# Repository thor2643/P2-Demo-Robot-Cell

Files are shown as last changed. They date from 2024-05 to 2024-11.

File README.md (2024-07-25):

# P2-Demo-Robot-Cell
This GitHub repository contains the relevant code and files for a robot demonstration cell initially developed by a second semester group at Aalborg University and later refined for robustness and visual appearance. The project aims to demonstrate how an entrance to autonomy does not necessarily have to be as expensive as one might think. This single robot cell stands in contrast to a bigger Festo demonstartion line which, like this robot cell, assembles a dummy phone. Beside this introduction to the cell, build and run instructions for the different applications are given to enable other persons or groups at Aalborg University to operate the cell. See the robot cell in action on [YouTube](https://youtu.be/gxAgMTmDVhU).
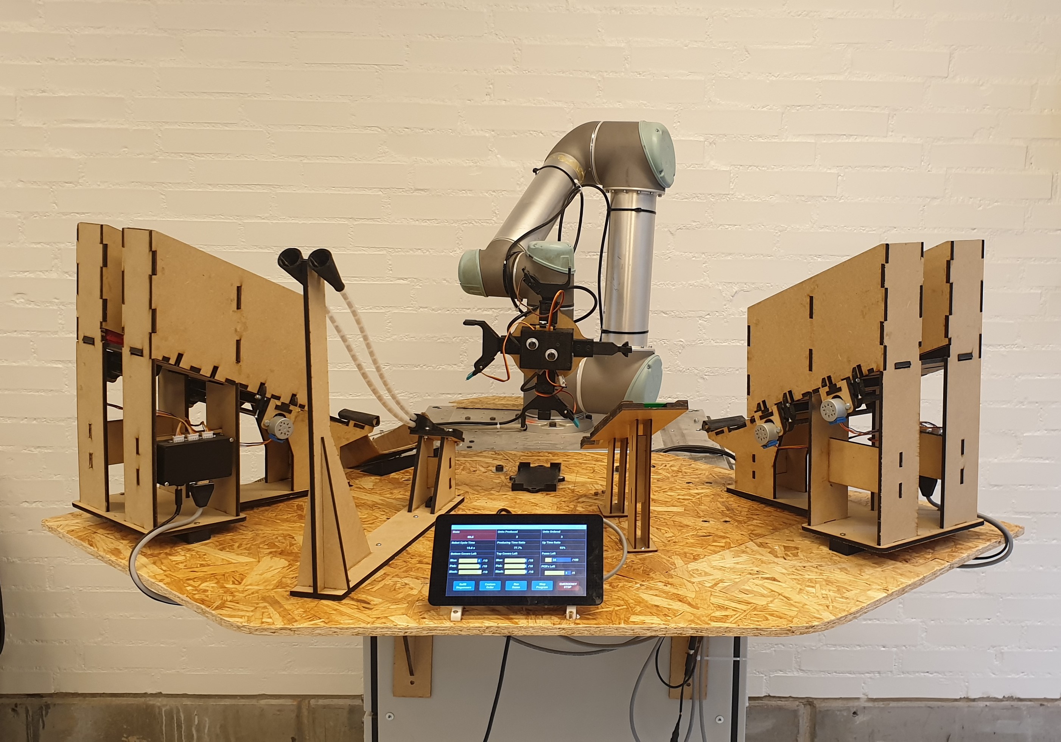
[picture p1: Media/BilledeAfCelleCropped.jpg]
Image of the whole robot cell


## How To Run the Cell
The first step to run the cell is making sure that everything is plugged in. There are three plugs that must be plugged into a power outlet: one for the robot, one for the Raspberry Pi and one for the dispensers. When the Raspberry Pi is plugged in it will automatically boot up and start the GUI application after some time. The next step is to start the right program on the UR5 robot. To do so, one must first initialise the robot by going the initialsation screen, turn ON the robot, START the robot, and holding the AUTO button until it is ready. Please notice that this old Polyscope version (1.8) moves a lot when initialising the robot, so make sure that the gripper is not close to any of the dispensers and the table; be careful when holding the AUTO button down. Before pushing AUTO the robot can be moved by hand by pushing the button on the backside of the teach pendant. Now the program can be loaded. Go to the main page and follow these steps:
1. Click "Program Robot"
2. Click "Load Program"
3. Find and open folder "P2-Demo"
4. Open "DemoProgram.urp"
5. Do not load installation file if asked (click "NO")
6. Go to "Installation" tab and choose "Load/Save" in the side panel
7. Click "Load" (Load a different installation file)
8. Open "demo.installation"
9. Go to "Program" tab and click play button to start the program

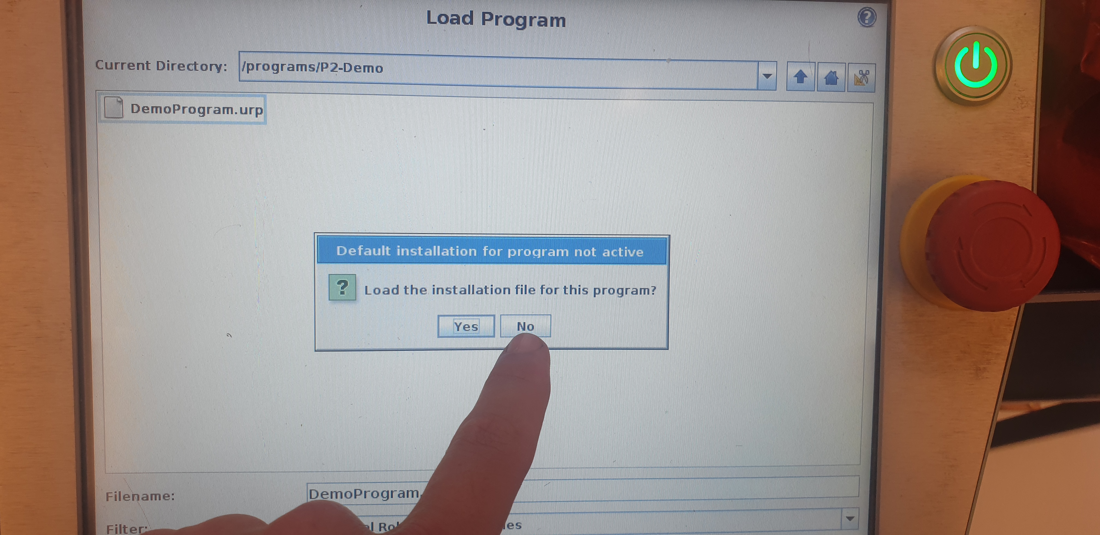
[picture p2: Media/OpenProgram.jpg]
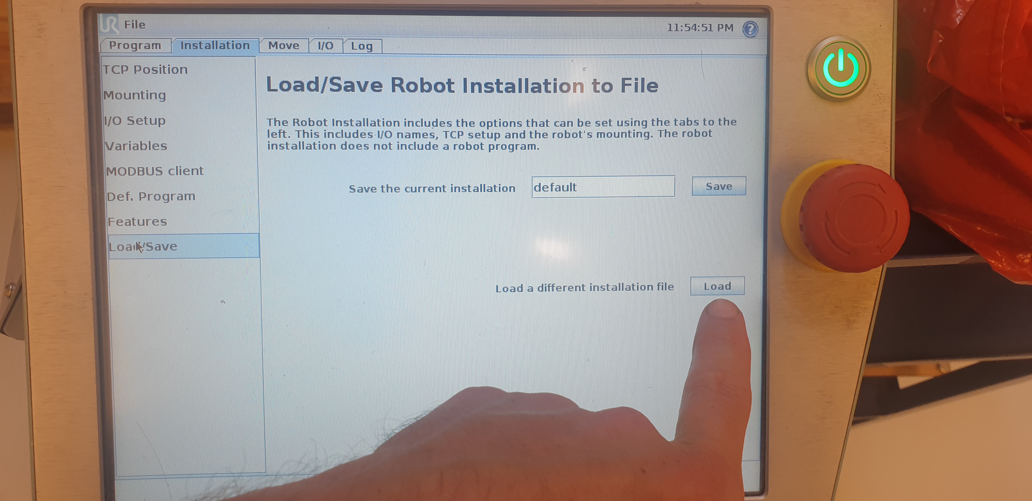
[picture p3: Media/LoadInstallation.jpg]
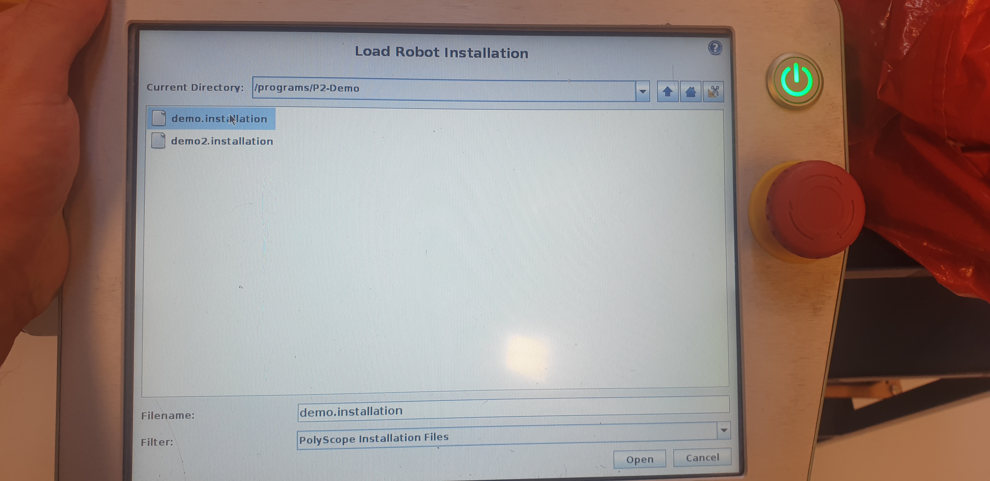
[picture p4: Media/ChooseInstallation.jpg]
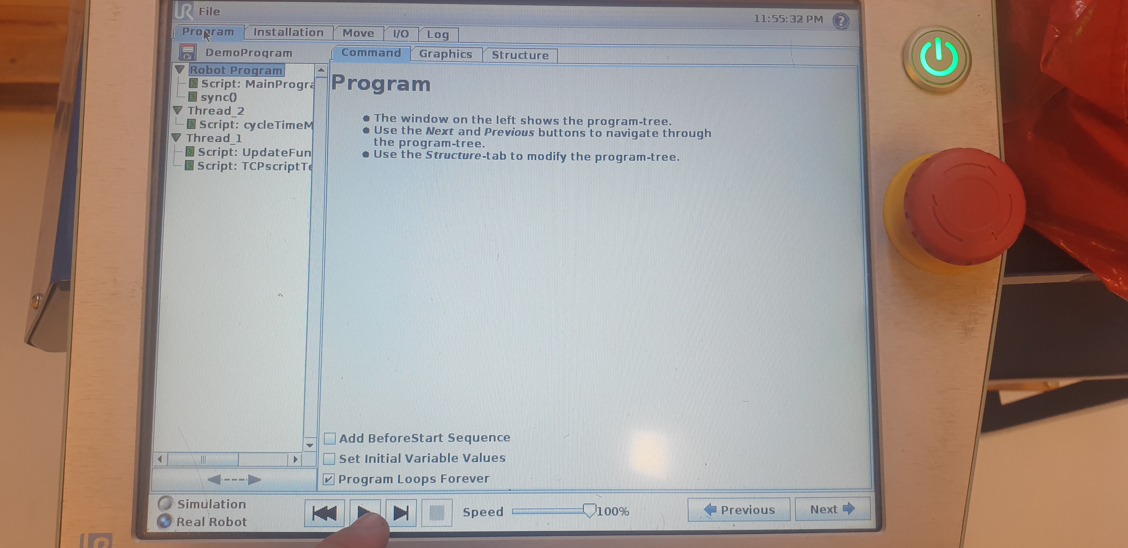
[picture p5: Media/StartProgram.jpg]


>[!Note]
>If the robot throws a force limit error the free move button on the backside must sometimes be pushed while enabling the robot to free it (can take a few tries). The socket connection to the Pi cannot always be reestablished by simply starting the program again. If this is the case the Raspberry Pi must be rebooted.
>Also please ensure that all grippers are opened before restarting program by going to the IO tab and turning ON/OFF pin 8 and 9 until all are opened.

## RoboDK 
A virtual copy of the robot cell has been created and vastly used throughout the programming of the robtos trajectory. By using the "Generate Program" feature, RoboDK generated the script, which with smaller modifications could be copied and run in the robot controller. The RoboDK station can be found in the "RoboDK" folder. To place the dispensers correctly and create proper target points a combination of the RoboDK python API and manually tweaking has been used, which has ensured a precise relation between the virtual cell and the physical cell. The created RoboDK program can, therefore, be well used if further development or modifcations to the cell setup or trajectory profile is desired. The scripts used to load and place the dispensers as well as creating the target points can be found in "Code/RoboDKScripts".
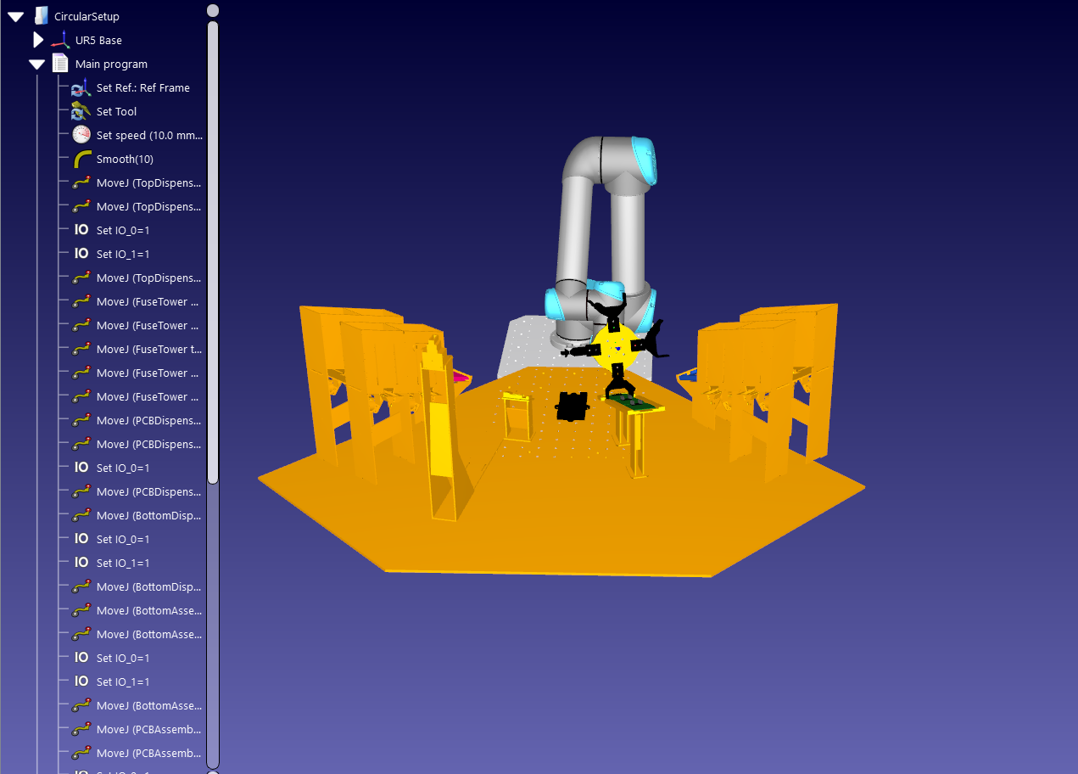
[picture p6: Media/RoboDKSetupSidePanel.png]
Screenshot of the RoboDK station.


## GUI Application Build Instructions
The GUI application has been developed to be cross-platform compatible and should therefore be buildable on both windows machines (using MSYS2) and linux machines. Build instructions are given to enable further development by other persons or groups. As an example, the custom order feature has not yet been implemented and could be a nice place to start learning about setup.  
To build the GUIServer application please refer to the comments written in "Code/TCPServer/GUIServer/MakeFile" to see GLFW dependency. When GLFW has been installed, the make command can called in the "GUIServer" folder to build the application. The executable can then be found in the test folder as GUIServerSmall.exe. 

>[!TIP]
>The App class structure for the ImGUI code has been set up following this tutorial on YouTube: [ImGUI code setup](https://www.youtube.com/watch?v=OYQp0GuoByM&t=1240s).

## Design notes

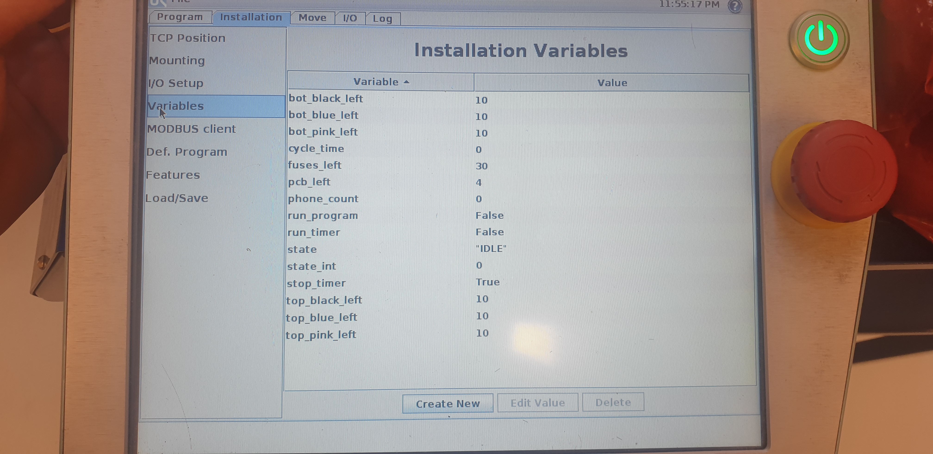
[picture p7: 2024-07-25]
Media/CheckVariables.jpg

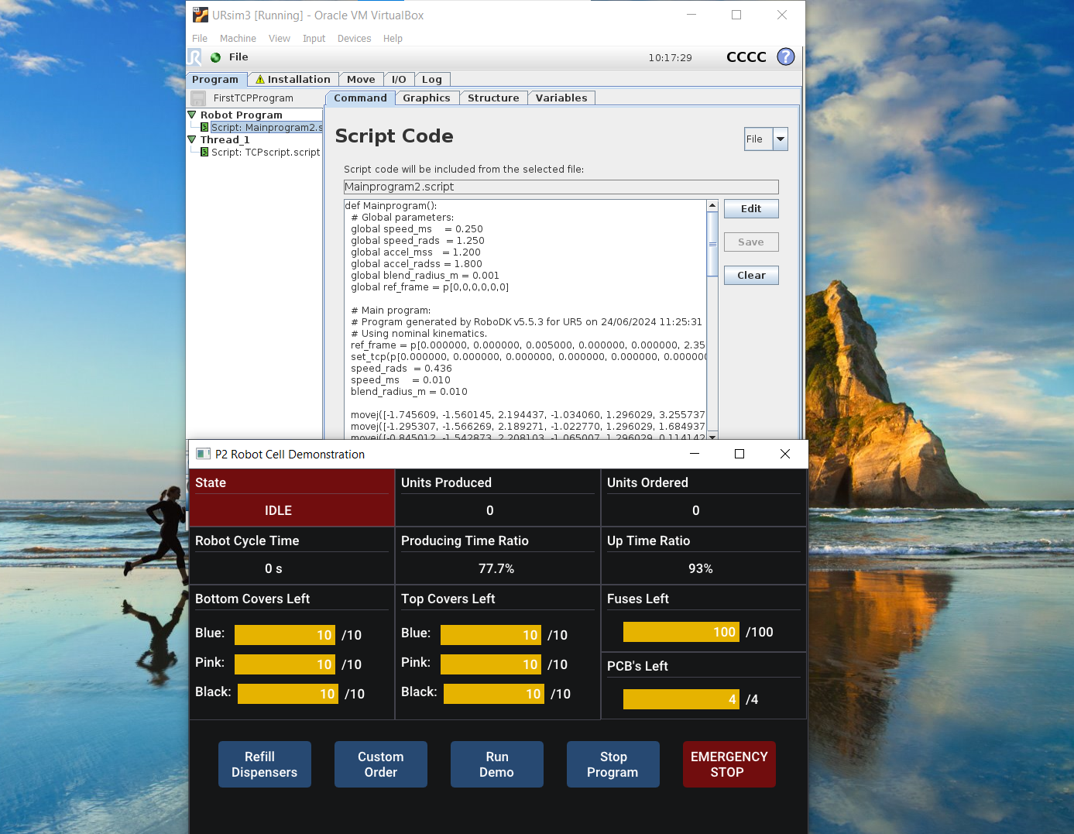
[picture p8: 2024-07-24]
Media/URSimAndGUI.png

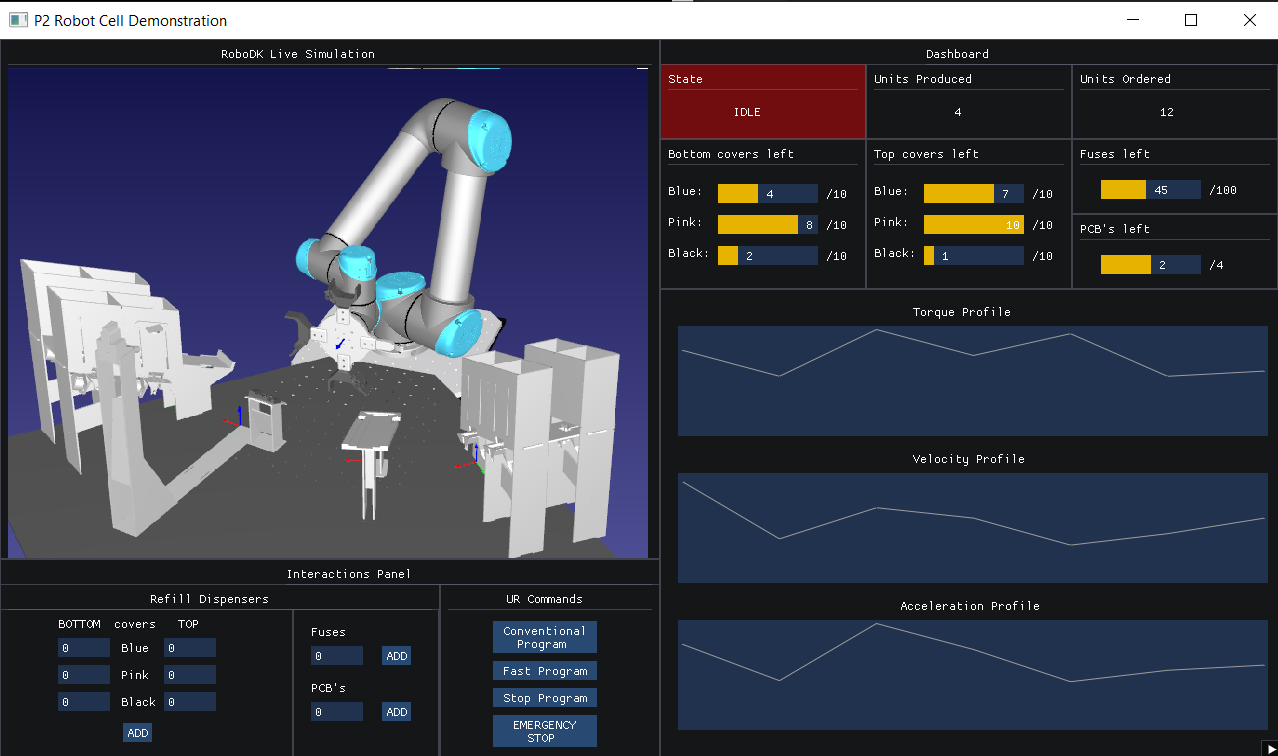
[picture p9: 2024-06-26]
Media/GUI_example.png

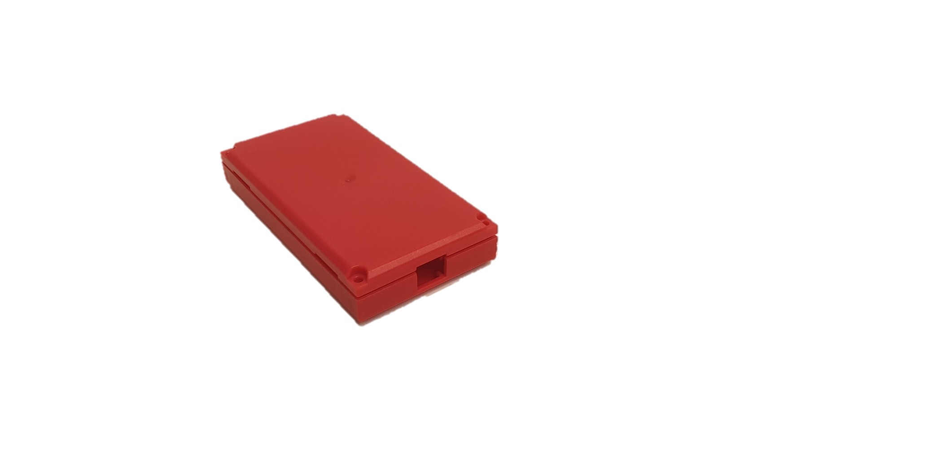
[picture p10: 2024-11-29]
Code/TCPServer/GUI_Server/resources/pink_pink.png

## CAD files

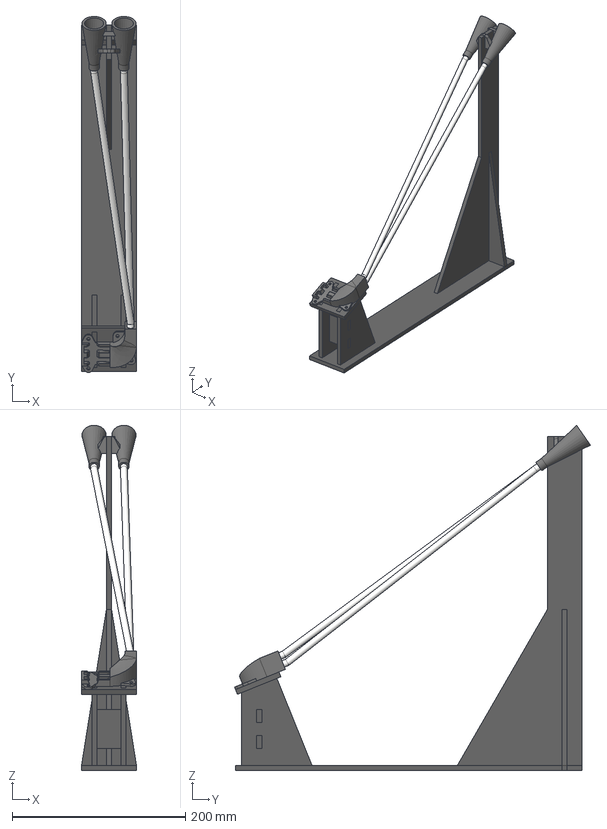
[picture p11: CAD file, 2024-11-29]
StepFiles/NewVersions/FuseDispenserAssembled.step
63.5 x 411.0 x 398.7 mm
BasePlate
LowerLegLeft
LowerLegRight
LowerSupport
Platform
UpperMainLeg
UpperSupport
FuseHolder
Funnel
PipeLeft
PipeRight

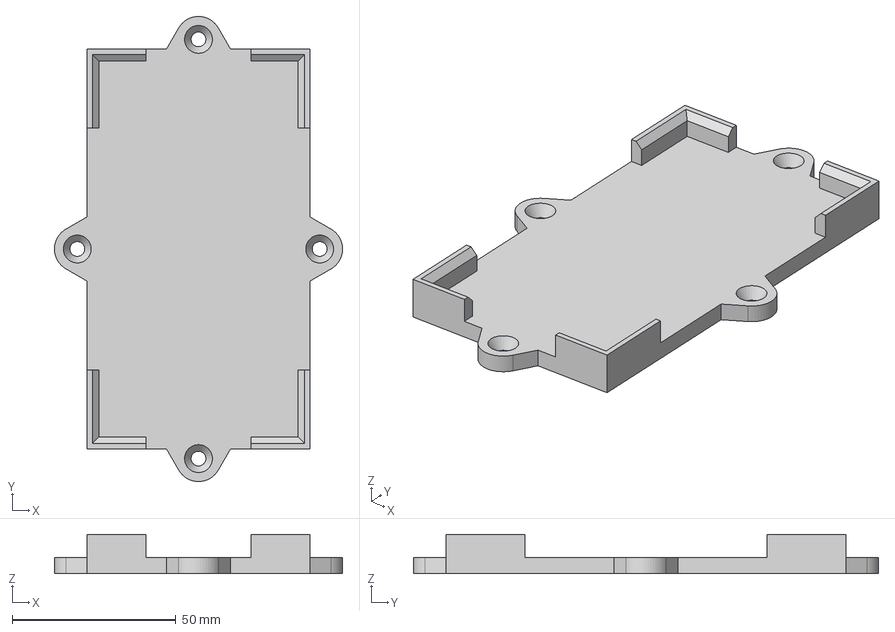
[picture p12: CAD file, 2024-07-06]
StepFiles/NewVersions/AssemblyHolder.step
88.0 x 142.0 x 12.0 mm

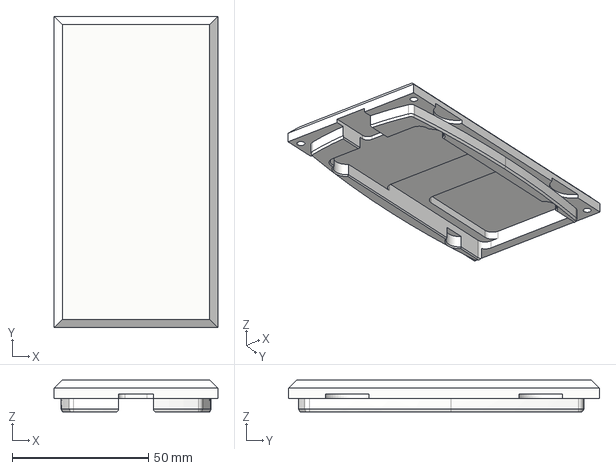
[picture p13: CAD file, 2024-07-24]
StepFiles/Top.step
60.0 x 114.0 x 11.7 mm

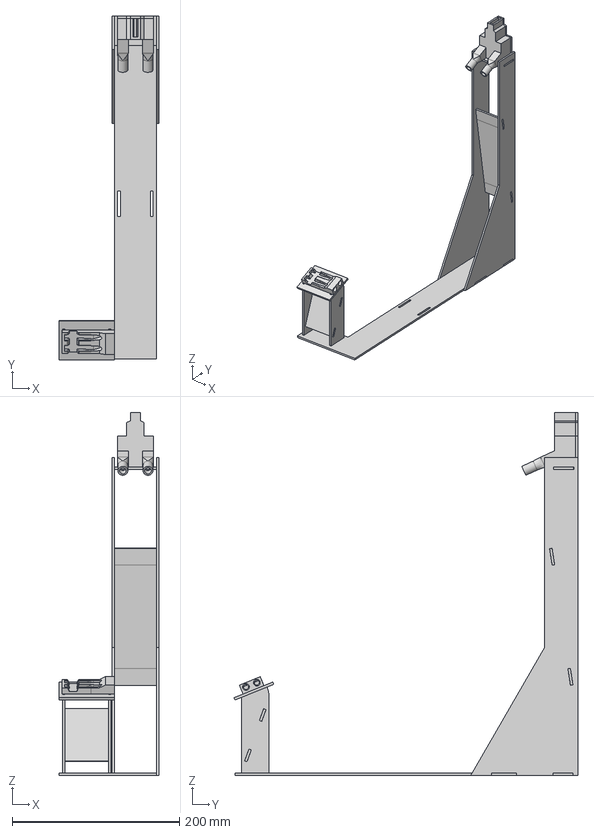
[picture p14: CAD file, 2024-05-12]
StepFiles/FuseTower.step
119.0 x 411.1 x 434.0 mm
Connection v3
Connection v3_1
Baseplate

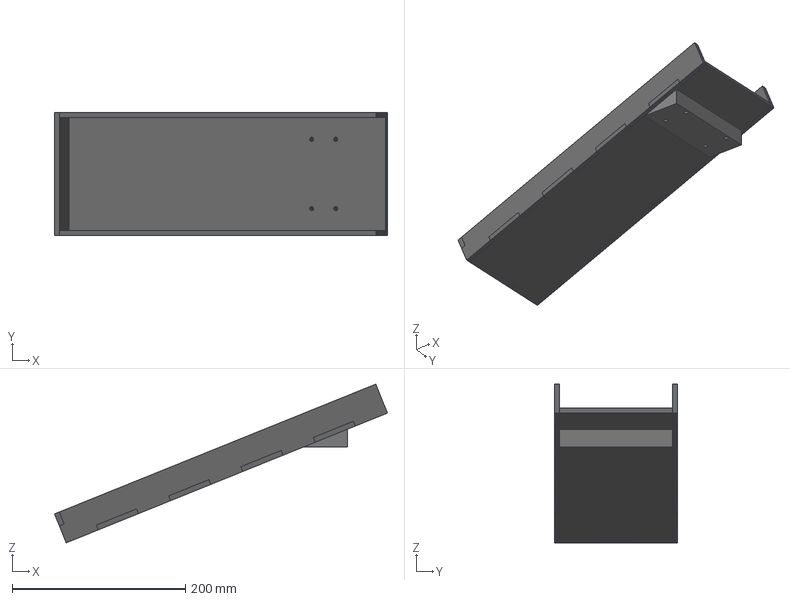
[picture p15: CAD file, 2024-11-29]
StepFiles/NewVersions/Unloader.step
384.4 x 142.0 x 183.2 mm

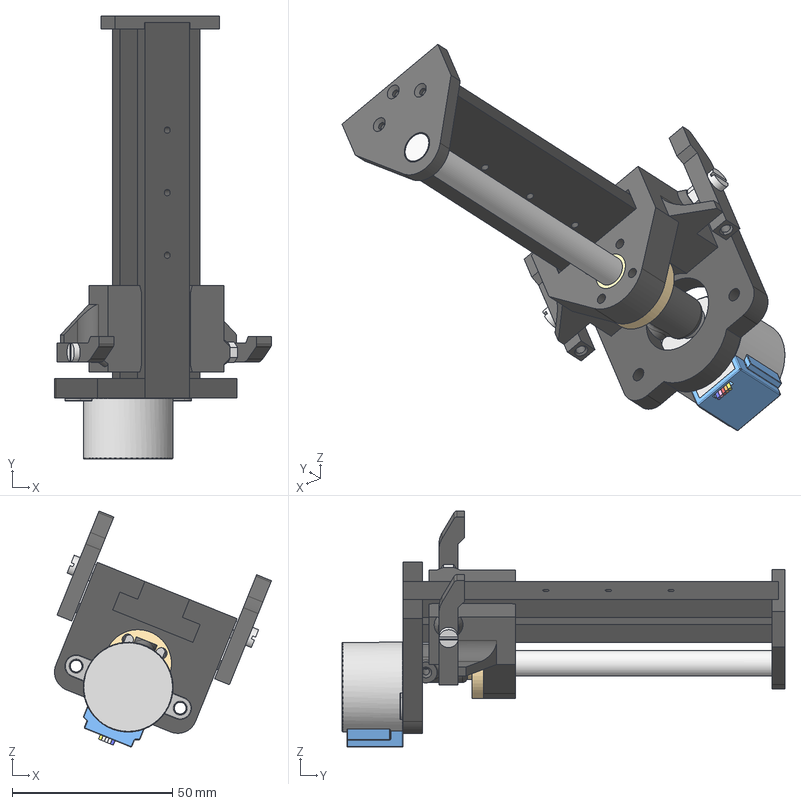
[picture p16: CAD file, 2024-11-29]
StepFiles/NewVersions/WidePusher.step
67.7 x 138.0 x 73.6 mm

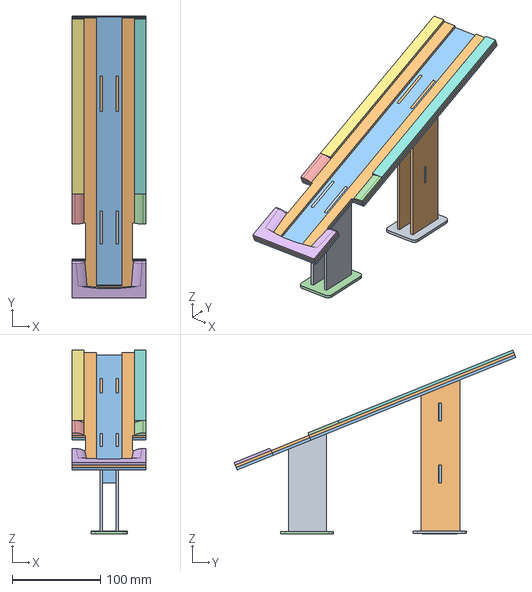
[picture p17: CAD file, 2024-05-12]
StepFiles/PCBDispenser.step
83.4 x 318.6 x 208.1 mm

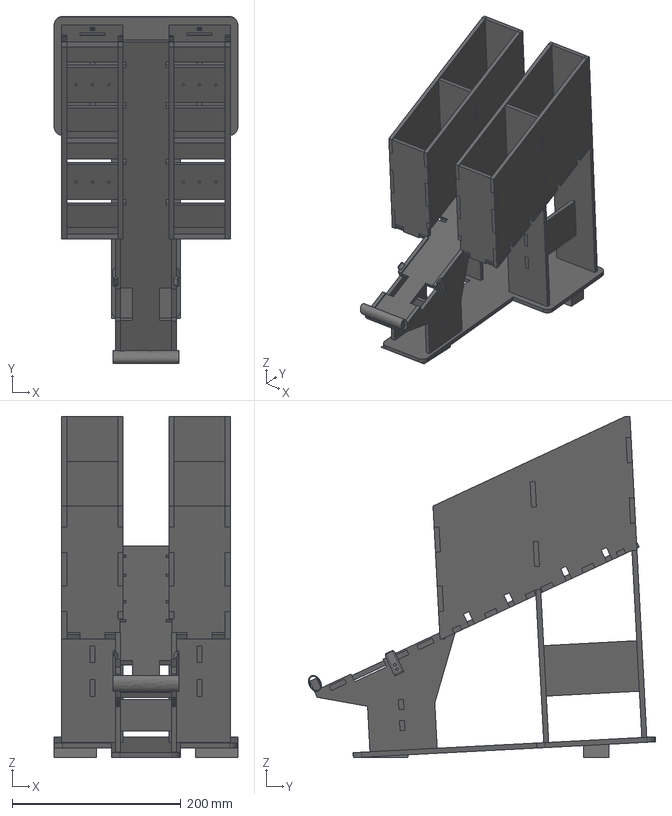
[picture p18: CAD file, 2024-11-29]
StepFiles/NewVersions/CoverContainer.step
218.0 x 411.7 x 405.0 mm

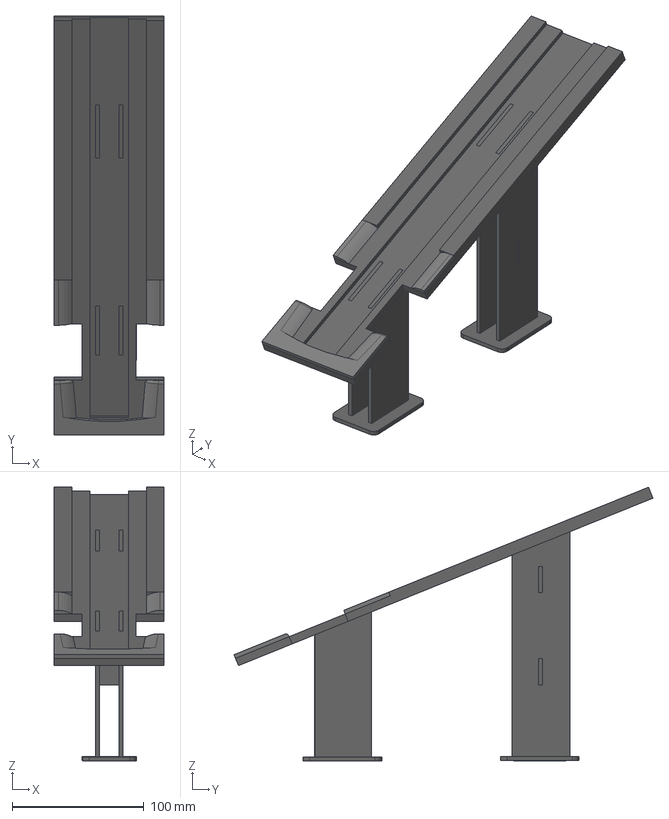
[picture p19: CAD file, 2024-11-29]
StepFiles/NewVersions/PCBSlider.step
83.4 x 318.6 x 208.1 mm

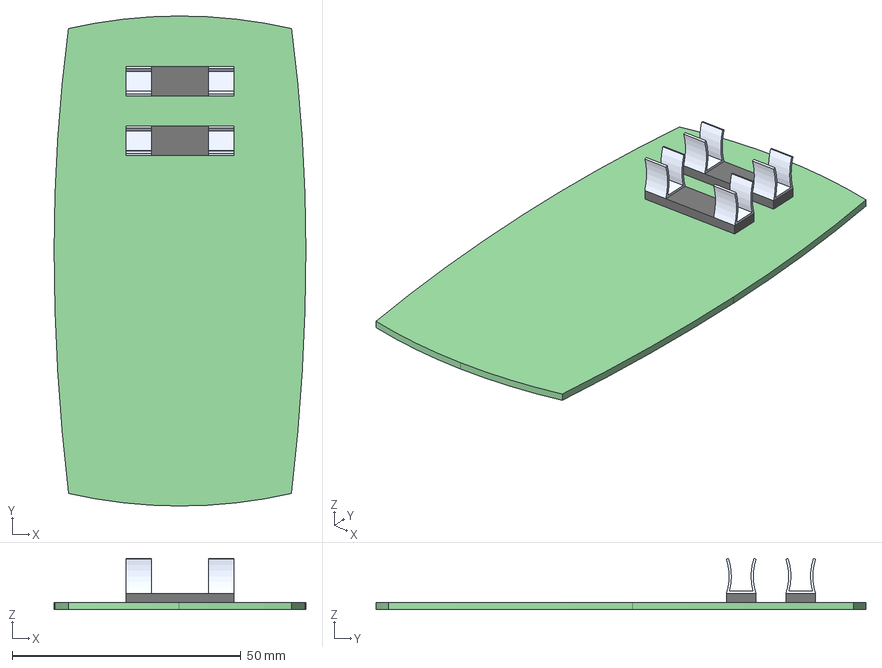
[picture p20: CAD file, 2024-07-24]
StepFiles/NewVersions/PCBBoard.step
55.0 x 107.0 x 11.2 mm

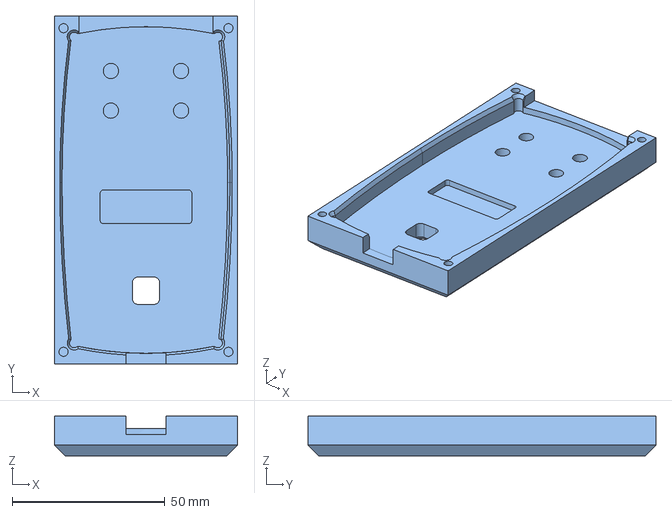
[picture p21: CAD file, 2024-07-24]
StepFiles/NewVersions/BundCover.step
60.0 x 114.0 x 13.0 mm

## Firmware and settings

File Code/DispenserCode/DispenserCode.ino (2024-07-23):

/*
  Example sketch to control a stepper motor with A4988 stepper motor driver, 
  AccelStepper library and Arduino: number of steps or revolutions. 
  More info: https://www.makerguides.com 
*/

// Include the AccelStepper library:
#include "AccelStepper.h"

// Motor interface type must be set to 1 when using a the A4988 driver or similar
#define motorInterfaceType 1

// Define stepper motor connections and motor interface type. 
#define stepPin_11 5
#define dirPin_11 22
#define enablePin_11 23

#define stepPin_12 3
#define dirPin_12 24
#define enablePin_12 25

#define stepPin_13 4
#define dirPin_13 26
#define enablePin_13 27

#define stepPin_21 8
#define dirPin_21 30
#define enablePin_21 31

#define stepPin_22 9
#define dirPin_22 32
#define enablePin_22 33

#define stepPin_23 10
#define dirPin_23 34
#define enablePin_23 35


// Create a new instance of the AccelStepper class:
/*
AccelStepper stepper_11 = AccelStepper(motorInterfaceType, stepPin_11, dirPin_11);
AccelStepper stepper_12 = AccelStepper(motorInterfaceType, stepPin_12, dirPin_12);
AccelStepper stepper_13 = AccelStepper(motorInterfaceType, stepPin_13, dirPin_13);
AccelStepper stepper_21 = AccelStepper(motorInterfaceType, stepPin_21, dirPin_21);
AccelStepper stepper_22 = AccelStepper(motorInterfaceType, stepPin_22, dirPin_22);
AccelStepper stepper_23 = AccelStepper(motorInterfaceType, stepPin_23, dirPin_23);

AccelStepper top_cover_motors[3] = {stepper_11, stepper_12, stepper_13};
AccelStepper bot_cover_motors[3] = {stepper_21, stepper_22, stepper_23};
*/

AccelStepper* top_cover_motors[3] = {0};
AccelStepper* bot_cover_motors[3] = {0};

int top_enable_pins[3] = {enablePin_11, enablePin_12, enablePin_13}; 
int bot_enable_pins[3] = {enablePin_21, enablePin_22, enablePin_23};

bool run = true;
bool top_done = false;
bool bot_done = false;
const int steps_per_revolution = 2048;
signed int steps_per_dispense = 10 * steps_per_revolution; //10 pr. dispense
signed int step_speed = 1400;
int step_acc = 300;



// A list with the double digits that are allowed, and the size of the list
int valid_combinations[9] = {11, 12, 13, 21, 22, 23, 31, 32, 33};
int valid_combinations_len = 9;

// An int and an int array, which will hold the motor_num being used, and the digits in the double digit
int motor_Num;
int digits[2];



void setup() {
    top_cover_motors[0] = new AccelStepper(motorInterfaceType, stepPin_11, dirPin_11);
    top_cover_motors[1] = new AccelStepper(motorInterfaceType, stepPin_12, dirPin_12);
    top_cover_motors[2] = new AccelStepper(motorInterfaceType, stepPin_13, dirPin_13);

    bot_cover_motors[0] = new AccelStepper(motorInterfaceType, stepPin_21, dirPin_21);
    bot_cover_motors[1] = new AccelStepper(motorInterfaceType, stepPin_22, dirPin_22);
    bot_cover_motors[2] = new AccelStepper(motorInterfaceType, stepPin_23, dirPin_23);

    // Set the maximum speed in steps per second:
    for (int i=0; i<3; i++){
        top_cover_motors[i]->setMaxSpeed(step_speed);
        bot_cover_motors[i]->setMaxSpeed(step_speed);

        top_cover_motors[i]->setAcceleration(step_acc);
        bot_cover_motors[i]->setAcceleration(step_acc);

        pinMode(top_enable_pins[i], OUTPUT);
        pinMode(bot_enable_pins[i], OUTPUT);

        // Disable all motors to avoid unnecessary current draw and noise.
        // Enabled when used.
        digitalWrite(top_enable_pins[i], HIGH);
        digitalWrite(bot_enable_pins[i], HIGH);
    }

    // Start serial communication
    Serial.begin(9600);
}

void loop() { 
    // Wait for a doubledigit to be received over the serial port. It is made into an integer
    if (Serial.available()) {
        motor_Num = Serial.parseInt();
        
        // As int casting rounds down this method works well to get the first digit. Second digit is found with modulus.
        digits[0] = (int)(motor_Num / 10);
        digits[1] = motor_Num % 10;

        // It is checked with the double digits is valid, meaning that is is contained within the combination list. If it is, 
        // then the digits will be passed on
        if (Is_Valid_Input(motor_Num)) {
            Stepper_Drive(digits[0], digits[1]);
            Serial.println("FINISHED");
        } else {
            Serial.println("ERROR");
        }

    }
}

// This function will use the split up double digit to drive the dispensing sequence by the requested stepper motors 
void Stepper_Drive(int top_motor_num, int bot_motor_num){
    int top_idx = top_motor_num - 1;
    int bot_idx = bot_motor_num - 1;

    // Activate respective motors
    digitalWrite(top_enable_pins[top_idx], LOW);
    digitalWrite(bot_enable_pins[bot_idx], LOW);

    //Serial.println(top_idx);
    //Serial.println((void)top_cover_motors[top_idx]);
    
    // Push the cover out and retreat
    for (int i=0; i<2; i++){
        // Will switch the sign for the two iterations. Push (-) and pull (+)
        step_speed = step_speed * -1;
        steps_per_dispense = steps_per_dispense * -1;


        // Firsly the speed is set for both the motors.
        //top_cover_motors[top_idx]->setSpeed(step_speed);
        //bot_cover_motors[bot_idx]->setSpeed(step_speed);

        // Set the current position to 0:
        top_cover_motors[top_idx]->setCurrentPosition(0);
        bot_cover_motors[bot_idx]->setCurrentPosition(0);

        // Firsly the speed is set for both the motors.
        top_cover_motors[top_idx]->moveTo(steps_per_dispense);
        bot_cover_motors[bot_idx]->moveTo(steps_per_dispense);

        top_done = false;
        bot_done = false;

        // Run the motors
        while(true)
        {   
            if (top_cover_motors[top_idx]->currentPosition() == steps_per_dispense){
                top_done = true;        
            } else {
                //top_cover_motors[top_idx]->setSpeed(step_speed);
                //top_cover_motors[top_idx]->runSpeed();
                top_cover_motors[top_idx]->run();
            }

            if (bot_cover_motors[bot_idx]->currentPosition() == steps_per_dispense){
                bot_done = true;        
            } else {
                //bot_cover_motors[bot_idx]->setSpeed(step_speed);
                //bot_cover_motors[bot_idx]->runSpeed();
                bot_cover_motors[bot_idx]->run();
            }

            if (top_done && bot_done){
                break;
            }
        }

        if (i==0){
            Serial.println("OUT");
        }

        delay(100);
    }

    // Deactivate respective motors
    digitalWrite(top_enable_pins[top_motor_num - 1], HIGH);
    digitalWrite(bot_enable_pins[bot_motor_num - 1], HIGH);
}

// This boolean function checks if the double digits are valid i.e. contained within the array.
bool Is_Valid_Input(int numb){
  for (int i = 0; i < valid_combinations_len; i++) {
    if (numb == valid_combinations[i]) {
      return true; // Return true if the number is found in the list
    }
  }
  return false; // Return false if the number is not found in the list
}

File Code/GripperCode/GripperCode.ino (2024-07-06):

#include <Servo.h>

Servo servoTop;  // create servo objects to control a servo
Servo servoBot;
Servo servoPCB;

#define servoSignal1 13 // blå - DO8 Tool_out_1
#define servoSignal2 12 // pink - DO9 Tool_out_0
 
bool new_state = false;

int pickupPosTop = 122;    // servo position when picking up object for the top cover
int releasePosTop = 170;   // servo position when releasing object for the top cover
int pickupPosBot = 102;    // servo position when picking up object for the bottom cover
int releasePosBot = 160;   // servo position when releasing object for the bottom cover
int pickupPosPCB = 133;    // servo position when picking up object for the PCB
int releasePosPCB = 170;   // servo position when releasing object for the PCB

int gripper_delay = 0;

int signalTop = 0;
int signalBot = 0;
int signalPCB = 0;

int pickupTopActive = 0;
int pickupBotActive = 0;
int pickupPCBActive = 0; 

int countTop = 0;
int countBot = 0;
int countPCB = 0;

unsigned long count = 0;
unsigned long prev_count = 0;

int signal1 = 0;       // signal1 and signal2 help initialising the pickup and release
int signal2 = 0;
int prev_signal1 = 0;
int prev_signal2 = 0;

void setup() {
  Serial.begin(9600);

  pinMode(servoSignal1, INPUT);
  pinMode(servoSignal2, INPUT);
  
  servoTop.attach(11);  // attaches the servo to pin 9, 10, and 11
  servoBot.attach(9);
  servoPCB.attach(10);

  servoTop.write(releasePosTop);
  servoBot.write(releasePosBot);
  servoPCB.write(releasePosPCB);
}

void loop() {
  readSignalValues();         // start each loop by reading for signals to initiate picking up object

  if (signalTop == 1 && new_state == true) {
    countTop++;
    if (pickupTopActive == 0 && countTop % 2 != 0) {
      Serial.println("Gør klar til at samle Top Cover op");
      servoTop.write(pickupPosTop);       // tell servo for top cover to go to pickup position
      pickupTopActive = 1;
      delay(gripper_delay);                       // waits 15ms for the servo to reach the position
    }
    if (pickupTopActive == 1 && countTop % 2 == 0) {
      Serial.println("Gør klar til at slippe Top Cover");
      servoTop.write(releasePosTop);      // tell servo for top cover to go to release position
      pickupTopActive = 0;
      delay(gripper_delay);                       // waits 15ms for the servo to reach the position
    }
    signalTop = 0;
    new_state = false;
  }
    
  if (signalBot == 1 && new_state == true) {
    countBot++;
    if (pickupBotActive == 0 && countBot % 2 != 0) {
      Serial.println("Gør klar til at samle Bottom Cover op");
      servoBot.write(pickupPosBot);       // tell servo for bottom cover to go to pickup position
      pickupBotActive = 1;
      delay(gripper_delay);                       // waits 15ms for the servo to reach the position
    }
    if (pickupBotActive == 1 && countBot % 2 == 0){
      Serial.println("Gør klar til at slippe Bottom Cover");
      servoBot.write(releasePosBot);      // tell servo to go to release position
      pickupBotActive = 0;
      delay(gripper_delay);                       // waits 15ms for the servo to reach the position
    }
    signalBot = 0;
    new_state = false;
  }

  if (signalPCB == 1 && new_state == true) {
    countPCB++;
    if (pickupPCBActive == 0 && countPCB % 2 != 0) {
      Serial.println("Gør klar til at samle PCB op");
      servoPCB.write(pickupPosPCB);       // tell servo to go to pickup position
      pickupPCBActive = 1;
      delay(gripper_delay);                       // waits 15ms for the servo to reach the position
    }
    if (pickupPCBActive == 1 && countPCB % 2 == 0){
      Serial.println("Gør klar til at slippe PCB");
      servoPCB.write(releasePosPCB);      // tell servo to go to release position
      pickupPCBActive = 0;
      delay(gripper_delay);                       // waits 15ms for the servo to reach the position
    }
    signalPCB = 0;
    new_state = false;
  }

}

void readSignalValues() {
  signal1 = digitalRead(servoSignal1);
  signal2 = digitalRead(servoSignal2);

  //delay(10);
  
  Serial.println(signal1);
  Serial.println(signal2);
  
  if (signal1 != 1 || signal2 != 1) {
    if (signal1 != prev_signal1 || signal2 != prev_signal2) {
      if (signal1 == 0 && signal2 == 1) { // signal for picking up top cover
        signalTop = 1;
        new_state = true;
      }
      
      if (signal1 == 1 && signal2 == 0) { // signal for picking up bottom cover
        signalBot = 1; 
        new_state = true;
      }
      
      if (signal1 == 0 && signal2 == 0) { // signal for picking up PCB cover
        signalPCB = 1;
        new_state = true;
      }
    }
  }

  prev_signal1 = signal1;
  prev_signal2 = signal2;
  
  //delay(250);
 
}

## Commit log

2024-05-12 Included and tested circular setup script
    [FuseTower.step, PCBDispenser.step]
2024-06-28 TCP socket code implemented and tested with URSim. Only tested on windows.
2024-07-03 fixes to run on raspberry
2024-07-04 RoboDK cell fitted for new setup
    [AssemblyHolder.step]
2024-07-09 Fix. Tested successfully with RPI
    [DispenserControl.py]
2024-07-23 fixed right cover updates
    [DispenserCode.ino]
2024-07-24 Added components to RoboDK and created UR program copy
    [BundCover.step, PCBBoard.step, Top.step]
2024-11-29 Updated step files and RoboDK
    [AssemblyHolder.step, BundCover.step, CoverContainer.step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]
